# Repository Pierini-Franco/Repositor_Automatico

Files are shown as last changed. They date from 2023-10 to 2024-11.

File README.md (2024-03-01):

# Repositor Automatico

## Index

* [Description](#description)
* [Demo and overview](#demo-and-overview)
* [Notes](#notes)

# Description
Autonomus warehouse robot capable of storing and bringing goods pallets using a realtime order products. The goal is to develop a system meant to automate warehouses and track the stock of the goods, as well as the employees's orders.

# Demo and overview
MQTT broker receiving employee's order in JSON format.

https://github.com/Pierini-Franco/Repositor_Automatico/assets/105557226/09ac5b65-eae8-4226-86f4-ccc1e2ff2913

The `React app` provides a way to order multiple products in a single order. At the same time, employees can order a single product 

| Order multiples products | Order a single product |
| :---: | :---: |
| client-and-mqtt-broker-gif-1 | client-and-mqtt-broker-gif-2 |

> [!NOTE]
> 
> _The React client order is sent throught websocket to a `Node.js server`, which re-send the products order to the `MQTT broker`_.

# Notes
This project is being develop and we will be posting the latest updates.

Leave a ⭐ if you are interested in this repo!

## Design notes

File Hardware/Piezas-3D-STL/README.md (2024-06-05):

# Piezas de impresion 3D

## Index

* [Descripcion](#descripcion)
* [Piezas 3D](#piezas-3d)
* [Notas](#notas)

# Descripcion
Conjunto de piezas del proyecto de impresion 3D

# Piezas 3D

| Nombre | Vista previa |
| :---: | :---: |
| Esquinero Base 1 |  |
| Sporte Motores |  |
| Soporte Placa CNY70 |  |

# Notas

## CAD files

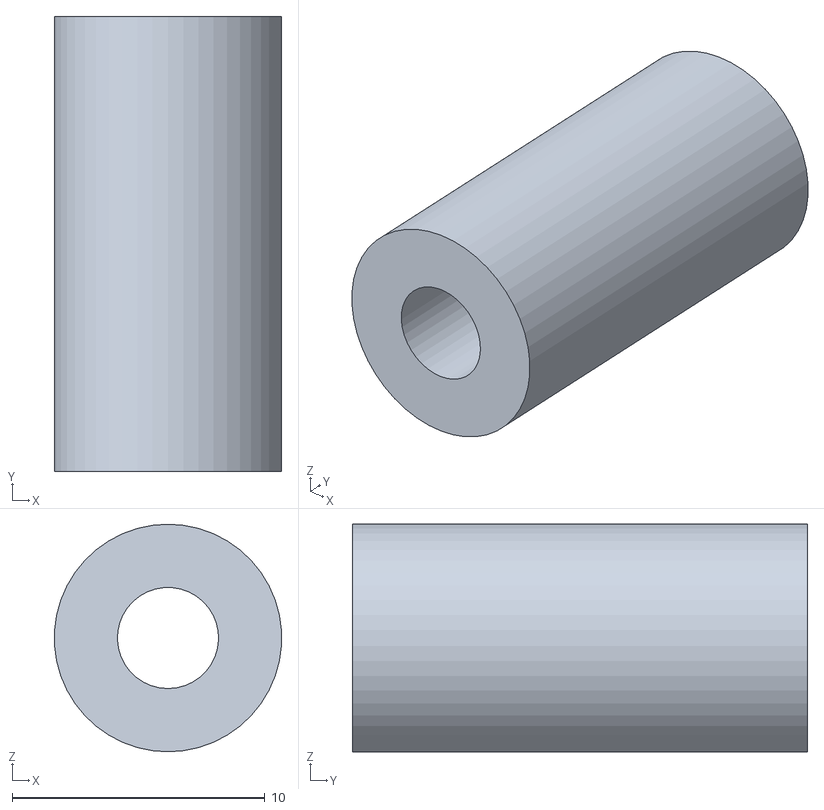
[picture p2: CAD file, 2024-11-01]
Hardware/Piezas-3D-STL/SOPORTE-PLACA-DRIVER-MAIN.STL
8.98 x 18.0 x 9.00

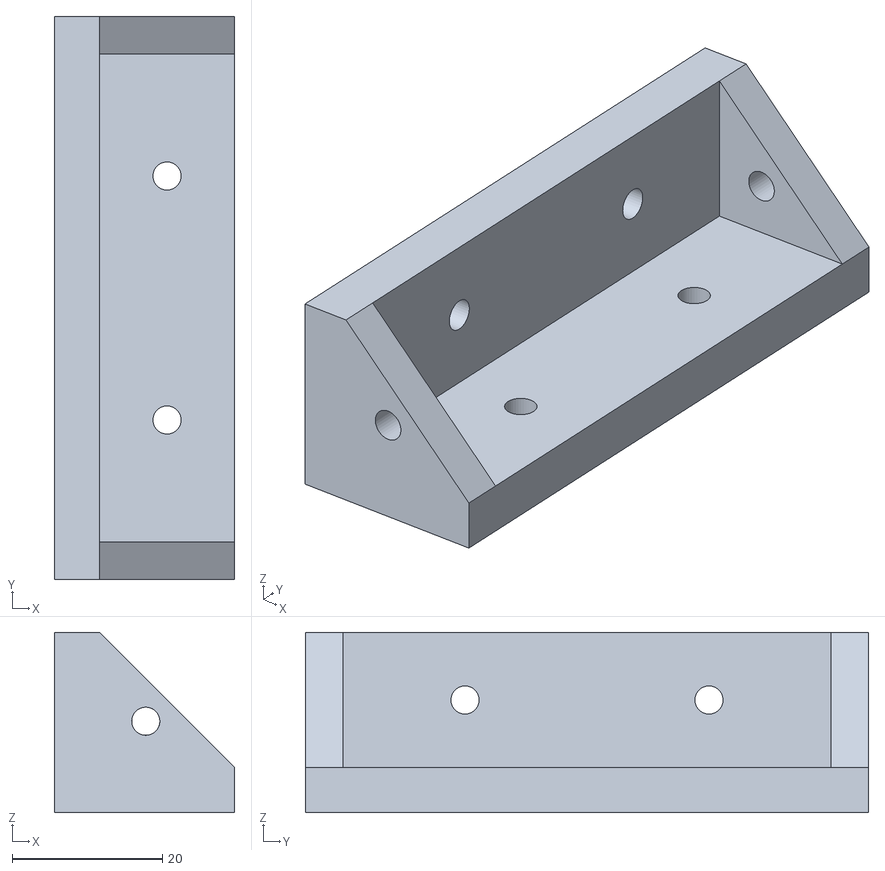
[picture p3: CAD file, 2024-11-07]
Hardware/Piezas-3D-STL/ESQUINERO-BASE-1-V2.STL
24.0 x 75.0 x 24.0

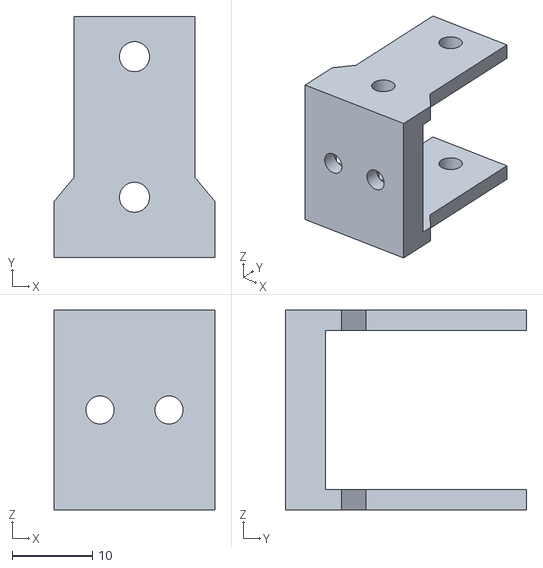
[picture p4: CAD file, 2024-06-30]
Hardware/Piezas-3D-STL/SOPORTE-MOTORES.STL
20.0 x 30.0 x 24.9

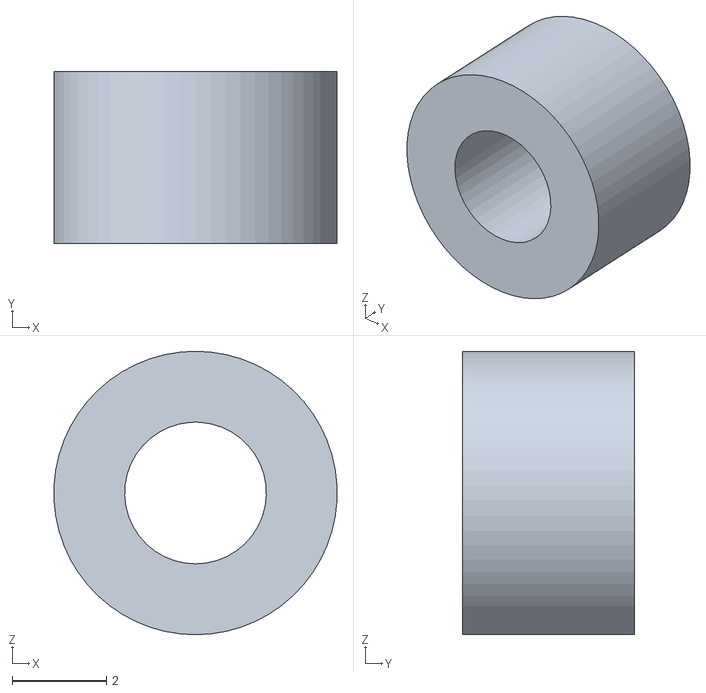
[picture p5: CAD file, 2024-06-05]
Hardware/Piezas-3D-STL/SOPORTE-PLACA-CNY70.STL
5.99 x 3.65 x 6.00

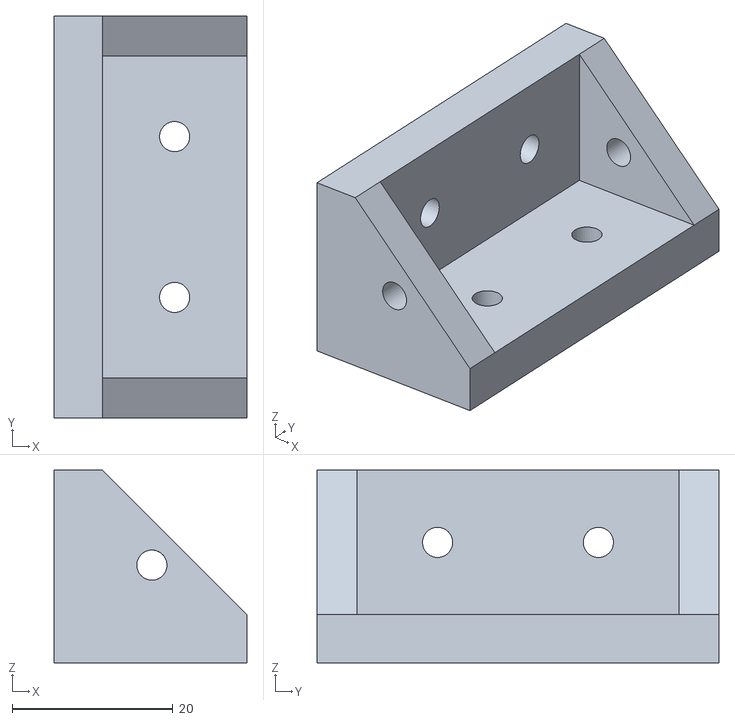
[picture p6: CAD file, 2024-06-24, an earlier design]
Hardware/Piezas-3D-STL/ESQUINERO-BASE-1.STL
24.0 x 50.0 x 24.0

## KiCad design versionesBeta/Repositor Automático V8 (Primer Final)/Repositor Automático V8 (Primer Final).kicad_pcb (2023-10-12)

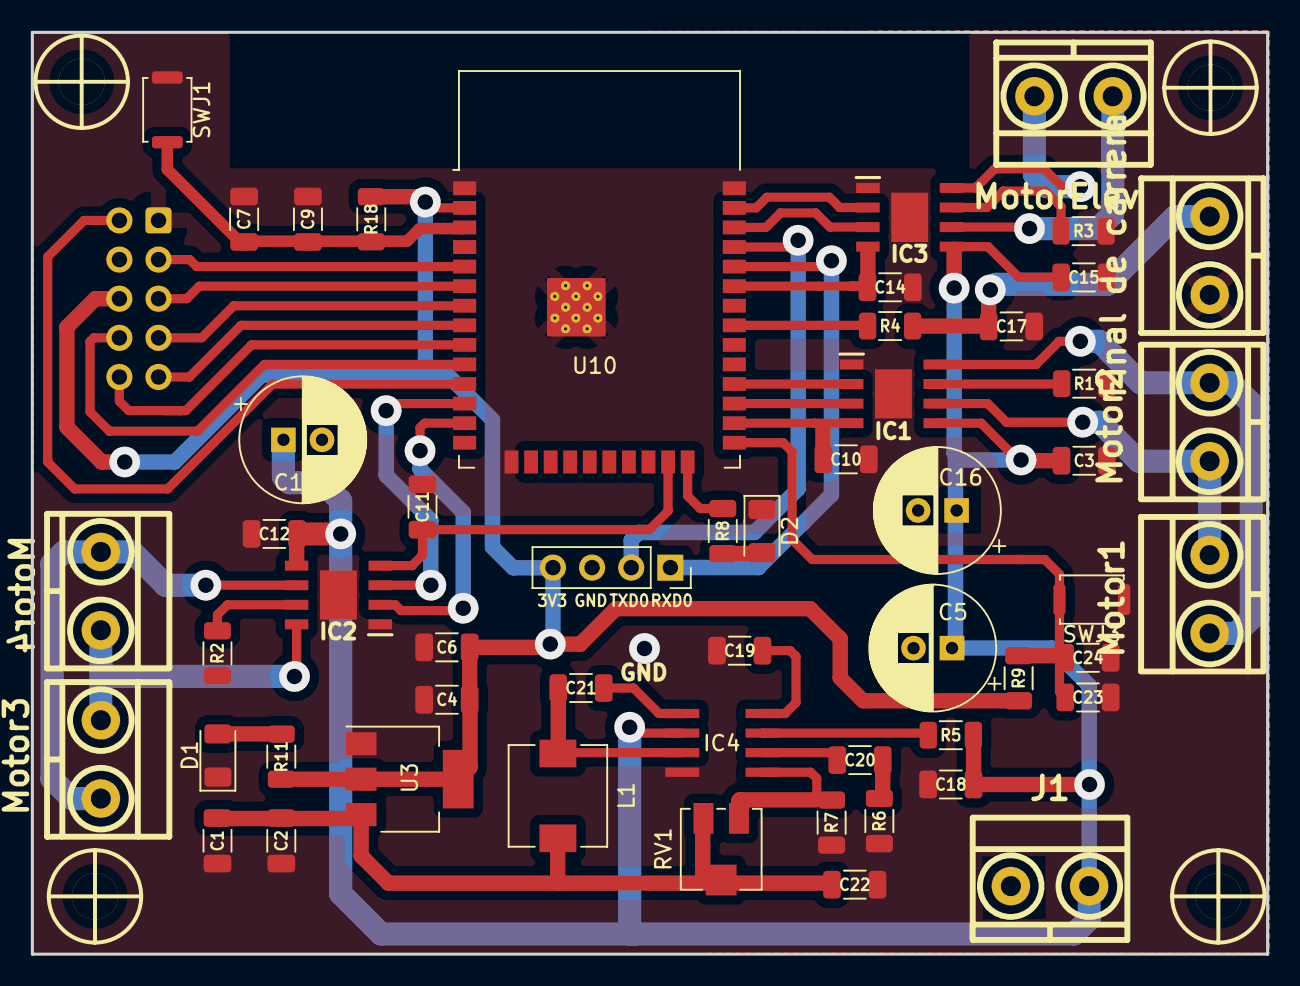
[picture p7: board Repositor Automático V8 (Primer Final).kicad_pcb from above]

Board: 2 copper layers, 80.2 x 59.8 mm, 59 parts (1 on the bottom side), 45 nets.

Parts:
C1, C6: 10u; C_1206_3216Metric
C2, C3, C4, C7, C9, C10, C11, C12, C14, C15, C17, C19, C23, C24: 0.1u; C_1206_3216Metric
C5, C13, C16: 100u; CP_Radial_D8.0mm_P2.50mm
C18, C22: 12u; C_1206_3216Metric
C20: 4.8n; C_1206_3216Metric
C21: 10n; C_1206_3216Metric
D1, D2: LED; LED_1206_3216Metric
IC1, IC2, IC3: TB67H450AFNG,EL; SOIC127P600X170-9N
IC4: MP2307; SO8-TH
J1: Alimentacion 12V; BORNERA2_AZUL
J2: UART; PinSocket_1x04_P2.54mm_Vertical
J3: Motor2; BORNERA2_AZUL
J4: Motor1; BORNERA2_AZUL
J5: Motor3; BORNERA2_AZUL
J6: Motor4; BORNERA2_AZUL
J7: MotorElev; BORNERA2_AZUL
J8: Screw_Terminal_01x10; IDC-Header_2x05_P2.54mm_Horizontal
J11: Final de carrera; BORNERA2_AZUL
L1: 2u; L_6.3x6.3_H3
R1, R2, R3: 0.22; R_1206_3216Metric
R4, R5: 100k; R_1206_3216Metric
R6, R7: 8.2k; R_1206_3216Metric
R8: 330; R_1206_3216Metric
R9, R18: 4.7k; R_1206_3216Metric
R11: 5.1k; R_1206_3216Metric
RV1: 220k; Potentiometer_Vishay_TS53YJ_Vertical
SWJ1, SWJ3: SW_MEC_5G; SW_Push_SPST_NO_Alps_SKRK
U3: AMS1117-3.3; SOT-223-3_TabPin2
U10: ESP32-WROOM-32; ESP32-WROOM-32D
hole_3mm, hole_3mm#2, hole_3mm#3, hole_3mm#4: VAL**; hole_3mm

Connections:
/3V3: C4.1, C6.1, J2.4, J8.6, R9.2, R11.1, R18.2, U3.2 (VO), U10.2 (VDD)
/5V: C1.1, C2.1, C22.1, L1.2, RV1.1, RV1.2, U3.3 (VI)
/BOOT: C23.2, C24.2, R9.1, SWJ3.2 (B), U10.25 (IO0)
/EN: C7.2, C9.2, R18.1, SWJ1.2 (B), U10.3 (EN)
/EN Elev: C14.1, IC3.4 (VREF), U10.33 (IO21)
/EnA: C10.1, IC1.4 (VREF), U10.26 (IO4)
/EnB: C11.1, IC2.4 (VREF), U10.23 (IO15)
/FC: R4.1, U10.31 (IO19)
/IN1: IC1.3 (IN1), U10.27 (IO16)
/IN2: IC1.2 (IN2), U10.28 (IO17)
/IN3: IC2.2 (IN2), U10.13 (IO14)
/IN4: IC2.3 (IN1), U10.12 (IO27)
/IN5: IC3.2 (IN2), U10.37 (IO23)
/IN6: IC3.3 (IN1), U10.36 (IO22)
/Led prueba: R8.1, U10.24 (IO2)
/RXD0: J2.1, U10.34 (RXD0/IO3)
/Sen1: J8.8, U10.10 (IO25)
/Sen2: J8.10, U10.9 (IO33)
/Sen3: J8.9, U10.8 (IO32)
/Sen4: J8.7, U10.7 (IO35)
/Sen5: J8.5, U10.6 (IO34)
/Sen6: J8.3, U10.5 (SENSOR_VN)
/Sen7: J8.2, U10.11 (IO26)
/TXD0: J2.2, U10.35 (TXD0/IO1)
/Vin: C3.1, C5.1, C12.1, C13.1, C15.1, C16.1, C18.1, IC1.5 (VM), IC2.5 (VM), IC3.5 (VM), IC4.2 (IN), J1.1, R5.1
GND: C1.2, C2.2, C3.2, C4.2, C5.2, C6.2, C7.1, C9.1, C10.2, C11.2, C12.2, C13.2, C14.2, C15.2, C16.2, C17.1, C18.2, C19.2, C22.2, C23.1, C24.1, D1.1 (K), D2.1 (K), IC1.1 (GND), IC1.9 (EP), IC2.1 (GND), IC2.9 (EP), IC3.1 (GND), IC3.9 (EP), IC4.4 (GND), J1.2, J2.3, J8.1, J11.2, R1.2, R2.2, R3.2, R6.1, R7.1, SWJ1.1 (A), SWJ3.1 (A), U3.1 (GND), U10.1 (GND), U10.15 (GND), U10.38 (GND), U10.39 (GND)
unnamed: C20.2, R6.2
unnamed: D1.2 (A), R11.2
unnamed: D2.2 (A), R8.2
unnamed: IC1.6 (OUT1), J3.1, J4.1
unnamed: IC1.8 (OUT2), J3.2, J4.2
unnamed: IC1.7 (RS), R1.1
unnamed: IC2.6 (OUT1), J5.1, J6.1
unnamed: IC2.8 (OUT2), J5.2, J6.2
unnamed: IC2.7 (RS), R2.1
unnamed: IC3.6 (OUT1), J7.1
unnamed: IC3.8 (OUT2), J7.2
unnamed: IC3.7 (RS), R3.1
unnamed: C21.1, IC4.1 (BS)
unnamed: C20.1, IC4.6 (COMP)
unnamed: IC4.7 (EN), R5.2
unnamed: IC4.5 (FB), R7.2, RV1.3
unnamed: C19.1, IC4.8 (SS)
unnamed: C21.2, IC4.3 (SW), L1.1
unnamed: C17.2, J11.1, R4.2

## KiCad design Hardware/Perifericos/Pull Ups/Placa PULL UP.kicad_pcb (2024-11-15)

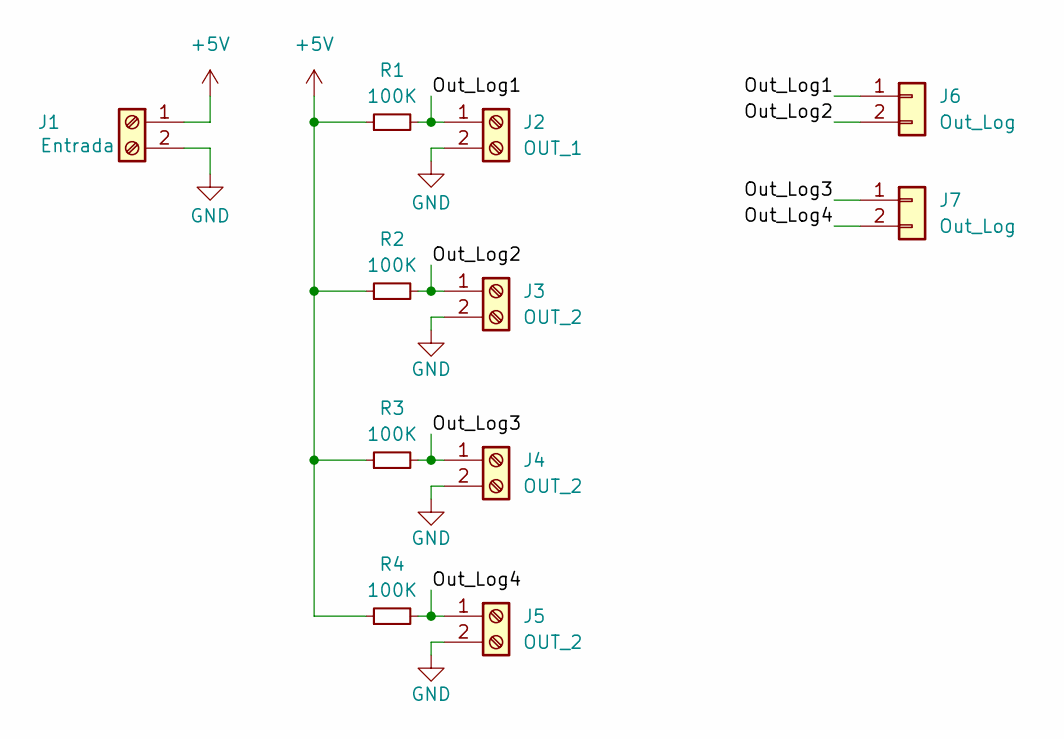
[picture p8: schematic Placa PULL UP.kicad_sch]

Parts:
J1: Entrada; BORNERA2_AZUL
J2: OUT_1; BORNERA2_AZUL
J3, J4, J5: OUT_2; BORNERA2_AZUL
J6, J7: Out_Log; PinHeader_1x02_P2.54mm_Horizontal
R1, R2, R3, R4: 100K; R_Axial_DIN0207_L6.3mm_D2.5mm_P7.62mm_Horizontal

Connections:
+5V: J1.1, R1.1, R2.1, R3.1, R4.1
/Out_Log1: J2.1, J6.1, R1.2
/Out_Log2: J3.1, J6.2, R2.2
/Out_Log3: J4.1, J7.1, R3.2
/Out_Log4: J5.1, J7.2, R4.2
GND: J1.2, J2.2, J3.2, J4.2, J5.2

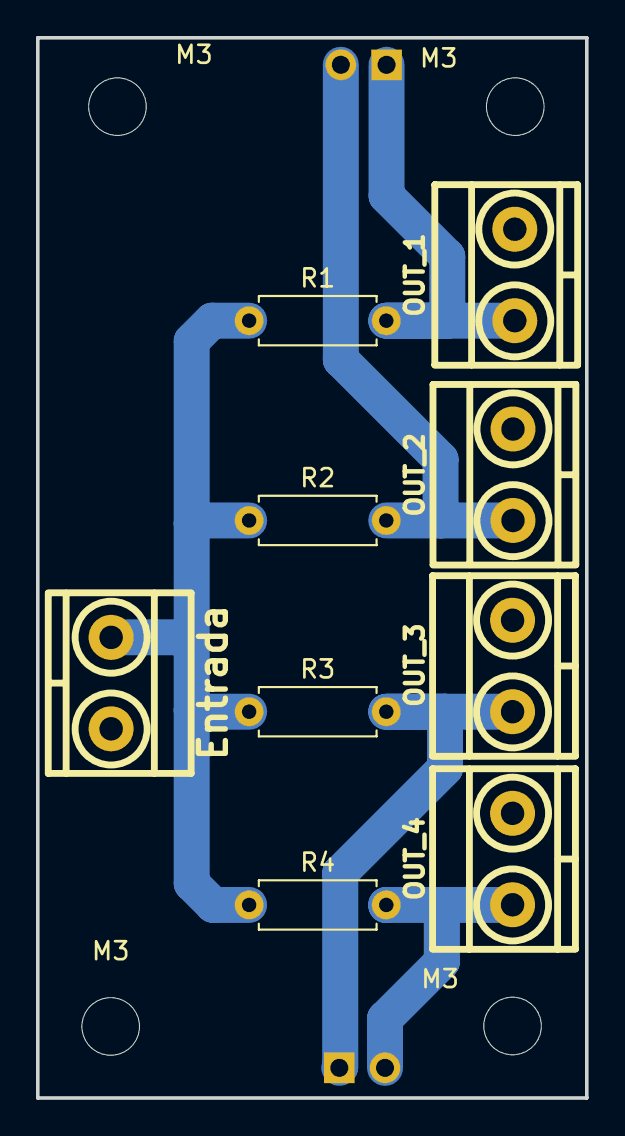
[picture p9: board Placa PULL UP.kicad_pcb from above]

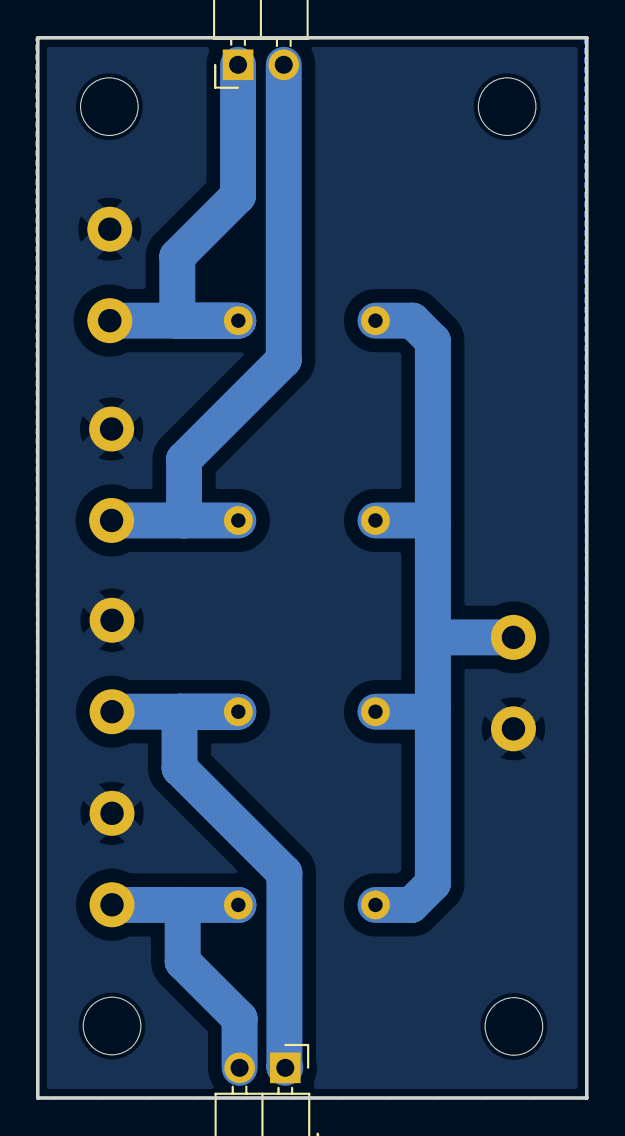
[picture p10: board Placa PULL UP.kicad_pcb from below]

Board: 2 copper layers, 30.5 x 58.9 mm, 15 parts (2 on the bottom side), 6 nets.

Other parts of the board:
M3, M3#2, M3#3, M3#4: MountingHole_3.2mm_M3

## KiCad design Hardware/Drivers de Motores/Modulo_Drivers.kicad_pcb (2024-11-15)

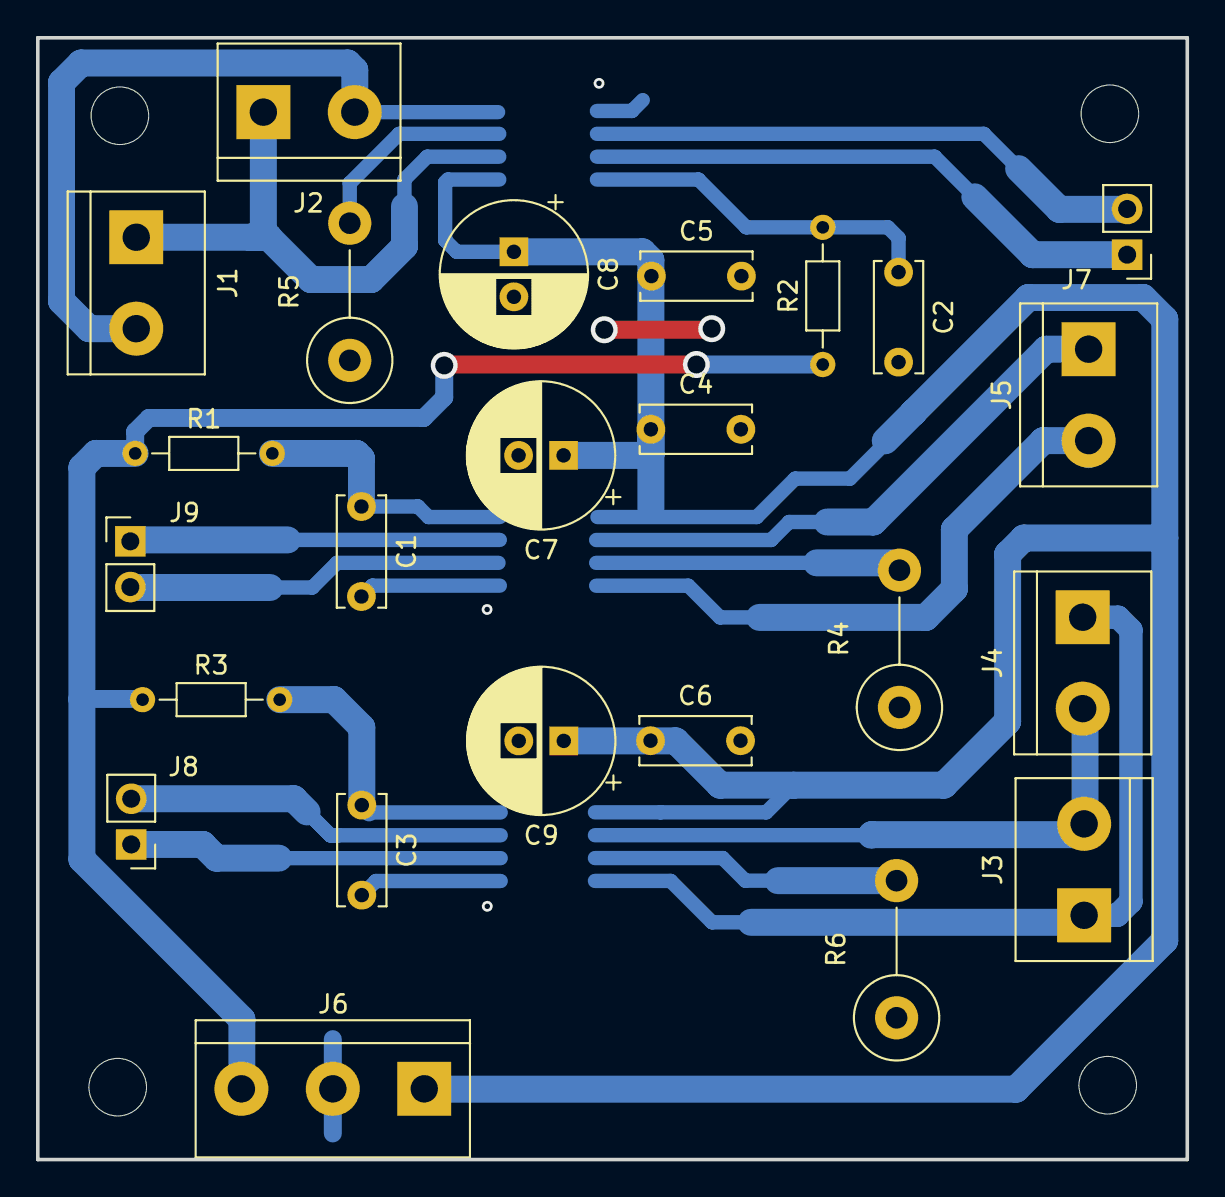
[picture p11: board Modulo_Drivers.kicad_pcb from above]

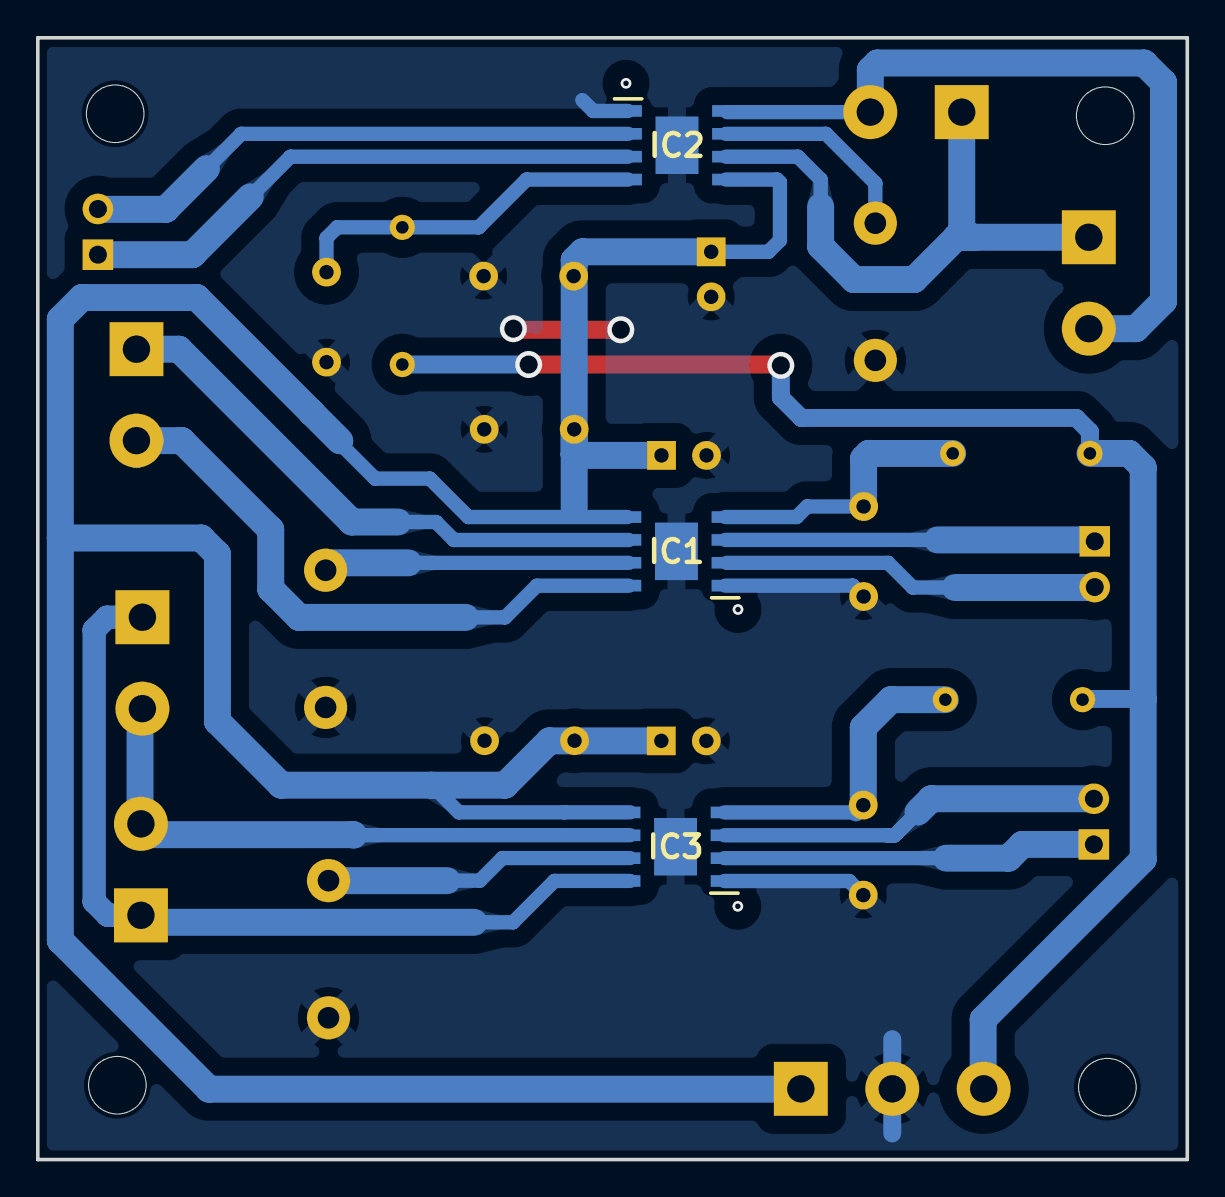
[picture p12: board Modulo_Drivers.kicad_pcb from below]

Board: 2 copper layers, 63.9 x 62.3 mm, 28 parts (3 on the bottom side), 21 nets.

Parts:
C1, C2, C3, C4, C5, C6: 0.1u; C_Disc_D6.0mm_W2.5mm_P5.00mm
C7, C8, C9: 100u; CP_Radial_D8.0mm_P2.50mm
IC1, IC2, IC3: TB67H450AFNG,EL; SOIC127P600X170-9N
J1: Motor1; TerminalBlock_bornier-2_P5.08mm
J2: Motor2; TerminalBlock_bornier-2_P5.08mm
J3: Motor3; TerminalBlock_bornier-2_P5.08mm
J4: Motor4; TerminalBlock_bornier-2_P5.08mm
J5: MotorElev; TerminalBlock_bornier-2_P5.08mm
J6: Alimentacion; TerminalBlock_bornier-3_P5.08mm
J7, J8, J9: Screw_Terminal_01x02; PinHeader_1x02_P2.54mm_Vertical
M3: MountingHole_3.2mm_M3
R1, R2, R3: 1k; R_Axial_DIN0204_L3.6mm_D1.6mm_P7.62mm_Horizontal
R4, R5, R6: 0,2; R_Axial_DIN0414_L11.9mm_D4.5mm_P7.62mm_Vertical

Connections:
/5V: J6.3, R1.1, R2.1, R3.1
/IN1: IC2.3 (IN1), J7.1
/IN2: IC2.2 (IN2), J7.2
/IN3: IC3.2 (IN2), J8.1
/IN4: IC3.3 (IN1), J8.2
/IN5: IC1.3 (IN1), J9.1
/IN6: IC1.2 (IN2), J9.2
/Vin: C4.1, C5.1, C6.1, C7.1, C8.1, C9.1, IC1.5 (VM), IC2.5 (VM), IC3.5 (VM), J6.1
GND: C1.2, C2.2, C3.2, C4.2, C5.2, C6.2, C7.2, C8.2, C9.2, IC1.1 (GND), IC1.9 (EP), IC2.1 (GND), IC2.9 (EP), IC3.1 (GND), IC3.9 (EP), J6.2, R4.1, R5.1, R6.1
unnamed: IC1.6 (OUT1), J5.1
unnamed: IC1.8 (OUT2), J5.2
unnamed: IC1.7 (RS), R4.2
unnamed: C1.1, IC1.4 (VREF), R1.2
unnamed: IC2.6 (OUT1), J1.1, J2.1
unnamed: IC2.8 (OUT2), J1.2, J2.2
unnamed: IC2.7 (RS), R5.2
unnamed: C2.1, IC2.4 (VREF), R2.2
unnamed: IC3.6 (OUT1), J3.2, J4.2
unnamed: IC3.8 (OUT2), J3.1, J4.1
unnamed: IC3.7 (RS), R6.2
unnamed: C3.1, IC3.4 (VREF), R3.2

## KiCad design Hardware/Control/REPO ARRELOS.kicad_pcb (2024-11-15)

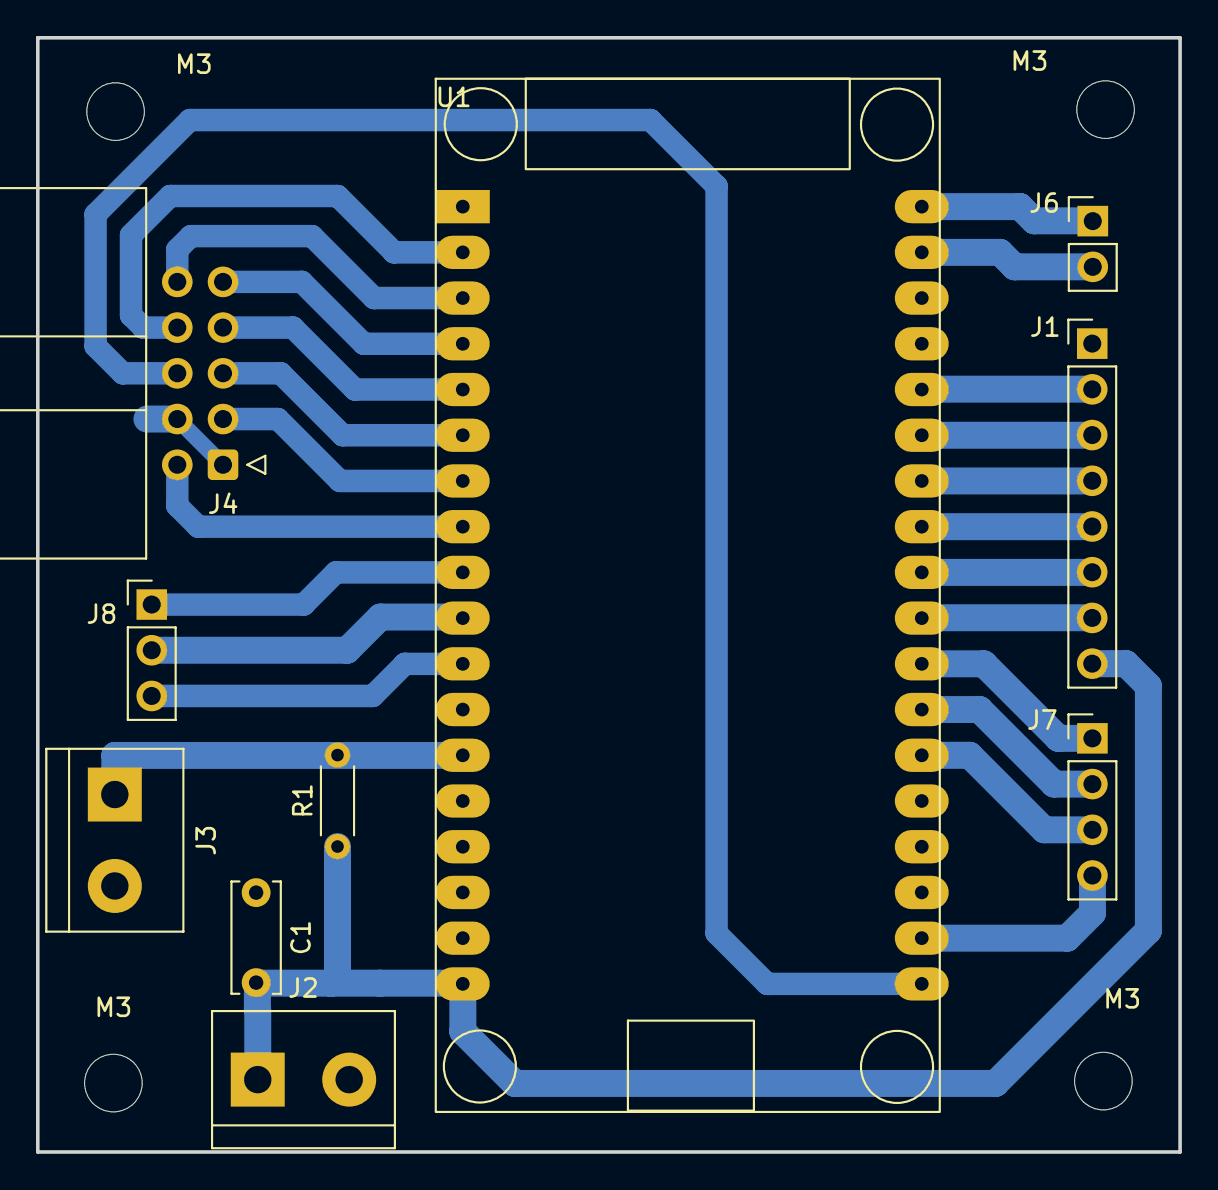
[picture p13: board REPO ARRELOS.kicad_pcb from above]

Board: 2 copper layers, 63.5 x 61.9 mm, 14 parts (0 on the bottom side), 26 nets.

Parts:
C1: 0.1u; C_Disc_D6.0mm_W2.5mm_P5.00mm
J1: Screw_Terminal_01x08; PinHeader_1x08_P2.54mm_Vertical
J2: IN STEP; TerminalBlock_bornier-2_P5.08mm
J3: FC; TerminalBlock_bornier-2_P5.08mm
J4: Screw_Terminal_01x10; IDC-Header_2x05_P2.54mm_Horizontal
J6: Screw_Terminal_01x02; PinHeader_1x02_P2.54mm_Vertical
J7: Screw_Terminal_01x04; PinHeader_1x04_P2.54mm_Vertical
J8: Screw_Terminal_01x03; PinHeader_1x03_P2.54mm_Vertical
M3, M3#2, M3#3, M3#4: MountingHole_3.2mm_M3
R1: 100k; R_Axial_DIN0204_L3.6mm_D1.6mm_P5.08mm_Horizontal
U1: ESP32_DevKit_V1_36PIN; ESP32_Devkit_V1_36pin

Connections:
/3V3: J4.6, U1.19 (3V3)
/5V: C1.2, J1.8, J2.1, R1.1, U1.18 (VIN)
/CLK: J7.4, U1.20 (CLK)
/FC: J3.1, R1.2, U1.13 (IO13)
/IN1: J1.2, U1.32 (IO21)
/IN2: J1.3, U1.31 (IO19)
/IN3: J1.4, U1.30 (IO18)
/IN4: J1.5, U1.29 (IO5)
/IN5: J1.6, U1.28 (TX2)
/IN6: J1.7, U1.27 (RX2)
/IO2(LED): J7.2, U1.25 (IO2)
/IO4: J7.1, U1.26 (IO4)
/IO14(BOOT PWM): J8.3, U1.11 (IO14)
/IO15(BOOT PWM): J7.3, U1.24 (IO15)
/IO22: J6.2, U1.35 (IO22)
/IO23: J6.1, U1.36 (IO23)
/IO26: J8.1, U1.9 (IO26)
/IO27: J8.2, U1.10 (IO27)
/Sen1: J4.8, U1.2 (SENSOR_VP)
/Sen2: J4.10, U1.3 (SENSOR_VN)
/Sen3: J4.9, U1.4 (IO34)
/Sen4: J4.7, U1.5 (IO35)
/Sen5: J4.5, U1.6 (IO32)
/Sen6: J4.3, U1.7 (IO33)
/Sen7: J4.2, U1.8 (IO25)
GND: C1.1, J1.1, J2.2, J3.2, J4.1, J4.4, U1.17 (GND)

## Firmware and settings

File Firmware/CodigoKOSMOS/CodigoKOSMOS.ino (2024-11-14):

#include <WiFi.h>
#include <PubSubClient.h>
#include "BluetoothSerial.h"
#define DEBUG 0
#define IN6 16
#define IN5 17
#define IN4 18
#define IN3 19
#define IN2 21
#define IN1 22
#define PIN_CNY1 36
#define PIN_CNY2 39
#define PIN_CNY3 34
#define PIN_CNY4 35
#define PIN_CNY5 32
#define PIN_CNY6 33
#define PIN_CNY7 25
#define FC1 4
#define FC2 26
#define FC3 27
#define led_ESP 2

#define derecha 1
#define izquierda 0
#define arriba 1
#define abajo 0

//Hardware
int x = 0; 
float anterior = 0, espera = 10, TIME;
int umbral = 1000; // negro > 1000
int var;
int ARRANCA;
int nivel;  
int destino;
int estado; 

// Canales PWM
#define CHA1 4
#define CHA2 5
#define CHB1 6
#define CHB2 7
#define CHC1 8
#define CHC2 9

#define FRQ 1000
#define RES 8
#define VEL 70


//Futbolista
/*int CT;
const int canalPWM0 = 0;
const int canalPWM1 = 1;
const int frecuencia = 10000;
const int resolucion = 8;  // Ciclo de trabajo de 0 a 255
String incoming, angulo;
char angulo1;
int modulo, boton;
BluetoothSerial BT;  // Objeto Bluetooth
*/
//conexion wifi
// WiFi 
//const char *ssid = "MovistarFibra-F76AF0"; // Enter your WiFi name
//const char *password = "cnvpmJkmdYrtNfX4ts2G";  // Enter WiFi password
//const char *ssid = "Franco's Galaxy A11"; // Introduce el nombre de tu WiFi 
//const char *password = "gkme2498";  // Introduce tu contraseña WiFi 
const char *ssid = "Taller_Electronica";
const char *password = "robotica";

WiFiClient espClient;                        // Definir espClient como un objeto de la clase WiFiClient. 


// MQTT Broker
int PAYLOADINT;
const char *mqtt_broker = "broker.emqx.io";
const char *topic = "KOSMOS"; //nombre a cambiar (nombre broker)
const char *mqtt_username = "KOSMOS_ESP"; //nombre a cambiar (nombre usuario)
const char *mqtt_password = "Repositor1"; //nombre a cambiar (nombre contraseña)
const int mqtt_port = 1883;
PubSubClient client(espClient);              // Definir espClient como objeto de la clase PubSubClient.


void setup() {
  Serial.begin(115200);         // Inicialización de la conexión en serie para la depuración
  pinMode(IN6, OUTPUT);  
  pinMode(IN5, OUTPUT);  
  pinMode(IN4, OUTPUT);  
  pinMode(IN3, OUTPUT);
  pinMode(IN2, OUTPUT);
  pinMode(IN1, OUTPUT);
  pinMode(led_ESP, OUTPUT);
  pinMode(PIN_CNY1, INPUT);
  pinMode(PIN_CNY2, INPUT);
  pinMode(PIN_CNY3, INPUT);
  pinMode(PIN_CNY4, INPUT);
  pinMode(PIN_CNY5, INPUT);
  pinMode(PIN_CNY6, INPUT);
  pinMode(PIN_CNY7, INPUT); 
  pinMode(FC1, INPUT); 
  pinMode(FC2, INPUT);
  pinMode(FC3, INPUT);

  //PWM
  ledcSetup(CHA1, FRQ, RES);
  ledcSetup(CHA2, FRQ, RES);
  ledcSetup(CHB1, FRQ, RES);
  ledcSetup(CHB2, FRQ, RES);
  ledcSetup(CHC1, FRQ, RES);
  ledcSetup(CHC2, FRQ, RES);

  ledcAttachPin(IN1, CHA1);
  ledcAttachPin(IN2, CHA2);
  ledcAttachPin(IN3, CHB1);
  ledcAttachPin(IN4, CHB2);
  ledcAttachPin(IN5, CHC1);
  ledcAttachPin(IN6, CHC2);
  
  //Conexion WIFI

  WiFi.begin(ssid, password);
  while (WiFi.status() != WL_CONNECTED) {
    delay(500);
    Serial.println("Connecting to WiFi..");
  }
  Serial.println("Connected to WiFi..");

  //Inicialización broker
  client.setServer(mqtt_broker, mqtt_port);
  client.setCallback(callback);
  while (!client.connected()) {
    String client_id = "esp32-client-";
    client_id += String(WiFi.macAddress());
    Serial.printf("The client %s connects to the public MQTT broker\n", client_id.c_str());
    if (client.connect(client_id.c_str(), mqtt_username, mqtt_password)) {
        Serial.println("Public EMQX MQTT broker connected");
        client.publish("Altura", "Hi EMQX I'm ESP32 ^^"); // Publish message upon successful connection
        digitalWrite (led_ESP, HIGH); 
    } else {
        Serial.print("failed with state ");
        Serial.print(client.state());
        delay(2000);
    }
    client.subscribe("Altura");
    client.subscribe("Direccion");
    client.subscribe("Iniciacion");
    client.subscribe("Estado");
  }

  //PARA FUTBOLISTA
  //BT.begin("ESP32_Kosmos");  // Nombre de su dispositivo Bluetooth y en modo esclavo
 /* ledcAttachPin(ENA, canalPWM0);  // hasta aca decia el video
  ledcAttachPin(ENB, canalPWM1);
  ledcSetup(canalPWM0, frecuencia, resolucion);
  ledcSetup(canalPWM1, frecuencia, resolucion);
 */
 //Charla esp
  client.publish(topic, "Hi, I'm ESP32 ^^");
  client.subscribe(topic);
}
void adelante() {
  ledcWrite(CHA1, VEL);
  ledcWrite(CHA2, 0);
  ledcWrite(CHB1, VEL);
  ledcWrite(CHB2, 0);
}
void atras() {
  ledcWrite(CHA1, 0);
  ledcWrite(CHA2, VEL);
  ledcWrite(CHB1, 0);
  ledcWrite(CHB2, VEL);
}
void doblarIzquierda() {
  ledcWrite(CHA1, VEL);
  ledcWrite(CHA2, 0);
  ledcWrite(CHB1, 0);
  ledcWrite(CHB2, 0);
}
void doblarDerecha() {
  ledcWrite(CHA1, 0);
  ledcWrite(CHA2, 0);
  ledcWrite(CHB1, VEL);
  ledcWrite(CHB2, 0);
}
void quieto(){
  ledcWrite(CHA1, 0);
  ledcWrite(CHA2, 0);
  ledcWrite(CHB1, 0);
  ledcWrite(CHB2, 0);
  ledcWrite(CHC1, 0);
  ledcWrite(CHC2, 0);
}
void subir(){
  ledcWrite(CHC1, VEL);
  ledcWrite(CHC2, 0);
}
void bajar(){
  ledcWrite(CHC1, 0);
  ledcWrite(CHC2, VEL);
}
bool tomar_objeto(int fc1){
  while (!fc1) subir(); 
  quieto(); 
  if (fc1) var = 1; 
  return var; 
}
int dejar_objeto(int fc1){
  while (fc1) bajar(); 
  quieto(); 
  if (!fc1) var = 1; 
  return var; 
} 
void giro180(int direccion){
  //arranca a girar, cuando volviste a leer blanco para tanto tiempo.
  TIME = millis();
  if (direccion == derecha) doblarDerecha(); 
  else doblarIzquierda();
  if(TIME - anterior > espera){
      anterior = TIME;

  while (!centro_negro()){
    if(direccion == derecha) doblarDerecha();
    else doblarIzquierda();
    }
    quieto();
  }
  if(TIME - anterior > espera){
    anterior = TIME;
    quieto(); 
  }
}
/*
void pruebaMotores(){
      digitalWrite(IN6, LOW );
        digitalWrite(IN5, HIGH);
        digitalWrite(IN4, LOW);
        digitalWrite(IN3, HIGH);
        digitalWrite(IN2, LOW);
        digitalWrite(IN1, HIGH);
        digitalWrite(ENA, HIGH);
        digitalWrite(ENB, HIGH);
        digitalWrite(ENC, HIGH);
}

void futbolista(){
  if (BT.available()) {
    incoming = BT.readStringUntil('#');
    angulo = incoming.substring(0, 1);
    angulo1 = angulo[0];
    boton = incoming.substring(1, 2).toInt();
  }
  Serial.println(incoming);
  //Serial.print("Recibido: ");
  if (DEBUG) BT.println(incoming);
  switch (angulo1) {
    case 'N':
      {
        digitalWrite(IN4, LOW);
        digitalWrite(IN3, HIGH);
        digitalWrite(IN2, LOW);
        digitalWrite(IN1, HIGH);
        if (DEBUG) BT.println("Adelante");
      }
      break;
    case 'S':
      {
        digitalWrite(IN4, HIGH);
        digitalWrite(IN3, LOW);
        digitalWrite(IN2, HIGH);
        digitalWrite(IN1, LOW);
        if (DEBUG) BT.println("Atras");
      }
      break;
    case 'E':
      {
        digitalWrite(IN4, LOW);

        digitalWrite(IN3, HIGH);
        digitalWrite(IN2, HIGH);
        digitalWrite(IN1, LOW);
        if (DEBUG) BT.println("Giro Derecha");
      }
      break;
    case 'W':
      {
        digitalWrite(IN4, HIGH);
        digitalWrite(IN3, LOW);
        digitalWrite(IN2, LOW);
        digitalWrite(IN1, HIGH);
        if (DEBUG) BT.println("Giro Izquierda");
      }
      break;
    case 'B':
      {
        digitalWrite(IN4, HIGH);
        digitalWrite(IN3, LOW);
        digitalWrite(IN2, LOW);
        digitalWrite(IN1, LOW);
        if (DEBUG) BT.println("PARA ATRAS A LA DERECHA");
      }
      break;
    case 'C':
      {
        digitalWrite(IN4, HIGH);
        digitalWrite(IN3, HIGH);
        digitalWrite(IN2, HIGH);
        digitalWrite(IN1, LOW);
        if (DEBUG) BT.println("PARA ATRAS A LA IZQUIERDA");
      }
      break;
    case 'A':
      {
        digitalWrite(IN4, LOW);
        digitalWrite(IN3, HIGH);
        digitalWrite(IN2, HIGH);
        digitalWrite(IN1, HIGH);
        if (DEBUG) BT.println("PARA ADELANTE A LA DERECHA");
      }
      break;
    case 'D':
      {
        digitalWrite(IN4, HIGH);
        digitalWrite(IN3, HIGH);
        digitalWrite(IN2, LOW);
        digitalWrite(IN1, HIGH);
        if (DEBUG) BT.println("PARA ADELANTE A LA IZQUIERDA");
      }
      break;
    case '0':
      {
        digitalWrite(IN4, LOW);
        digitalWrite(IN3, LOW);
        digitalWrite(IN2, LOW);
        digitalWrite(IN1, LOW);
        if (DEBUG) BT.println("FRENA");
      }
      break;
  }
  switch (boton)  // vamos a darle velocidad con esto.
  {
    case 4:
      {
        CT = 255;
        ledcWrite(canalPWM0, CT);
        ledcWrite(canalPWM1, CT);
      }
      break;
    case 3:
      {
        CT = 216;
        ledcWrite(canalPWM0, CT);
        ledcWrite(canalPWM1, CT);
      }
      break;
    case 2:
      {
        CT = 192;
        ledcWrite(canalPWM0, CT);
        ledcWrite(canalPWM1, CT);
      }
      break;
    case 1:
      {
        CT = 127;
        ledcWrite(canalPWM0, CT);
        ledcWrite(canalPWM1, CT);
      }
      break;
    case 0:
      {
        CT = 0;
        ledcWrite(canalPWM0, CT);
        ledcWrite(canalPWM1, CT);
      }
  }
}*/
void lecturaCNY_prueba() {
  Serial.println(analogRead(PIN_CNY1));
  Serial.println(analogRead(PIN_CNY2));
  Serial.println(analogRead(PIN_CNY3));
  Serial.println(analogRead(PIN_CNY4));
  Serial.println(analogRead(PIN_CNY5));
  Serial.println(analogRead(PIN_CNY6));
  Serial.println(analogRead(PIN_CNY7));
  delay(200);
}
bool es_negro(int pin){
  int sumatoria = 0; 
  for (int i=0; i<5; i++){
    sumatoria += analogRead(pin);  
  }
  int promedio = sumatoria / 5;
  return promedio > umbral;
}

bool centro_negro(){
  var = es_negro(PIN_CNY3) && es_negro(PIN_CNY4) && es_negro(PIN_CNY5); 
  return var;
}

bool bifurcacion(){
  var = es_negro(PIN_CNY6) && es_negro(PIN_CNY7); 
  return var;
}

bool cod_llegue(){
  var = es_negro(PIN_CNY1) && es_negro(PIN_CNY2) && es_negro(PIN_CNY3) && es_negro(PIN_CNY4) && es_negro(PIN_CNY5) && es_negro(PIN_CNY6) && es_negro(PIN_CNY7); 
  return var;
}

bool cod_volver(){
  var =es_negro(PIN_CNY1) && es_negro(PIN_CNY3) && es_negro(PIN_CNY4) && es_negro(PIN_CNY5) && es_negro(PIN_CNY6);  
  return var;
}

bool cod_izq(){
  var =es_negro(PIN_CNY1) && es_negro(PIN_CNY2) && es_negro(PIN_CNY3) && es_negro(PIN_CNY4) && es_negro(PIN_CNY5);  
  return var;
}

bool cod_salir(){
  var =es_negro(PIN_CNY2) && es_negro(PIN_CNY3) && es_negro(PIN_CNY4) && es_negro(PIN_CNY5) && es_negro(PIN_CNY7); 
  return var;
}

int contador(){
  //contador, devuelve derecha o izquierda y lee sensores para ver que llego
  //tomar dato de la base de datos (¿Cuando doblo, en que bifurcación?)
  //esto es para IR al destino

  //destino = dato_base;   
  if (bifurcacion()){
    int x = x+1; 
  }
  if (x == destino){
    doblar(derecha); 
    return 1; 
  } 
}

void doblar(int direccion) {
TIME = millis();
  if (direccion == derecha) doblarDerecha(); 
  else doblarIzquierda();
  if(TIME - anterior > espera){
      anterior = TIME;

  while (!centro_negro()){
    if(direccion == derecha) doblarDerecha();
    else doblarIzquierda();
    }
  }
  quieto();
  if(TIME - anterior > espera){
    anterior = TIME; 
    quieto();
  }
}

void salir (int ARRANCA){
  TIME = millis();
  if (ARRANCA){
  while (!cod_salir()){
  atras(); 
  }  
  quieto();   
  if(TIME - anterior > espera)
    {
      anterior = TIME; 
      giro180(derecha);  
    }
  }
}

void volver (){
  TIME = millis();
  while (!cod_volver()) atras();   
  quieto();   
  if(TIME - anterior > espera)
    {
      anterior = TIME; 
      giro180(izquierda);  
    }
  }


void giro_vuelta(){
  TIME = millis();
  while (!cod_izq) doblarIzquierda();
  quieto(); 
  if(TIME - anterior > espera){
    anterior = TIME; 
    quieto();
  }
} 

int nivelar_pala (int nivel, int fc2){
  //Corregir
  // Me va a entrar por base de datos en q gondola (arriba o abajo) va el objeto. Para subir y bajar vamos a usar tiempo y alguna barrera fisica
  TIME = millis();
  int espera1 = 500; //a definir cuando sepamos cuanto es necesario para poner bien la pala
  if(TIME - anterior > espera1){
  anterior = TIME;
  if (nivel==1){
    while (!fc2){
    subir();
    var = 1;  
    }
  }  
  else{ 
    var = 0; 
    } 
  }
  quieto(); 
  if(TIME - anterior > espera){
    anterior = TIME; 
    quieto();
  }
  return var; 
}
void devolver_pala(int fc3){
  TIME = millis();
  while (!fc3){
  bajar(); 
  }
  quieto();
  if(TIME - anterior > espera){
    anterior = TIME; 
    quieto();
  }
}
void depositar_objeto(){  

  //pruebaMotores();  
  //FC da 1 cuando detecta algo
  //Salir de la estacion y nivelar pala
  //Salir de la estacion: poner marca para hacer giro 180°, establecer si estoy yendo o volviendo 
  //Por ahora estoy programando para ir a buscar algo, no traerlo
  //La base de datos me va a decir: gondola a la que ir, altura, yendo a bucar o trayendo, me dice ARRANCA

  //TODOOO ESTO ES PARA IR
  //int ARRANCA = 1;
  //int nivel = 1;  
  //ARRANCA, nivel me lo va a dar la base de datos
  int estado_objeto = 0; 
  int estado_pala = 0; 
  int fc1 = 0;
  int fc2 = 0;
  int fc3 = 0;
   
  fc1 = digitalRead(FC1);
  fc2 = digitalRead(FC2);
  fc3 = digitalRead(FC3);  
  if (ARRANCA == 1){
  if (tomar_objeto(fc1)){
  salir (ARRANCA);
  estado_pala = nivelar_pala(nivel, fc2); 
    } 
  while (centro_negro()){
  if (contador()){
    while (!cod_llegue()){
    adelante();
    }
    quieto(); 
   estado_objeto = dejar_objeto(fc1); 
  }
  else {adelante();}
  }

  //VOLVEEER
  if (estado_objeto){
 volver();  
  }
  while (!cod_llegue()) adelante(); 
  quieto(); 
  giro_vuelta(); 
  while (!cod_llegue()) adelante();
  quieto(); 
  if (estado_pala) devolver_pala(fc3);
  quieto();  
  }
}

void extraer_objeto(){

  //int ARRANCA = 1;
  int nivel = 0;
  int destino = 2;   
  //ARRANCA, nivel me lo va a dar la base de datos
  //IR
  int estado_objeto = 0; 
  int fc1 = 0;
  int fc2 = 0;
  int fc3 = 0;
   
  fc1 = digitalRead(FC1);
  fc2 = digitalRead(FC2);
  fc3 = digitalRead(FC3);  

  if (ARRANCA){
  salir (ARRANCA);
  int estado_pala = nivelar_pala(nivel, fc2); 
  while (centro_negro()){
  if (contador()){
    while (!cod_llegue()){
    adelante();
    }
    quieto(); 
    estado_objeto = tomar_objeto(fc1); 
  }
  else adelante();
  }

  //VOLVER
  if (estado_objeto){
 volver();  
  }
  while (!cod_llegue()) adelante(); 
  quieto(); 
  giro_vuelta(); 
  while (!cod_llegue()) adelante();
  quieto();
  dejar_objeto(fc1); 
  quieto(); 
  }
}
void callback(char *topic, byte *payload, unsigned int length) {
  //La base de datos me va a decir: gondola a la que ir, altura, yendo a bucar o trayendo, me dice ARRANCA
  //Hacer otros if con otros topicos para las otras cosas a guardar. Hace un topico, confirma y va a otro topico.
  if (strcmp (topic, "Altura")==0){
    char payload_string[ length + 1]; 
    memcpy (payload_string, payload, length);  
    payload_string[length] = '\0'; 
    PAYLOADINT = atoi(payload_string);
    Serial.println(PAYLOADINT); 
    nivel = PAYLOADINT; 
  }
  else if (strcmp (topic, "Direccion")==0){
    char payload_string[ length + 1]; 
    memcpy (payload_string, payload, length); 
    payload_string[length] = '\0'; 
    PAYLOADINT = atoi(payload_string); 
    Serial.println(PAYLOADINT);
    destino = PAYLOADINT; 
  }
  else if (strcmp (topic, "Estado")==0){
    char payload_string[ length + 1]; 
    memcpy (payload_string, payload, length); 
    payload_string[length] = '\0'; 
    PAYLOADINT = atoi(payload_string); 
    Serial.println(PAYLOADINT);
    estado = PAYLOADINT; 
  }
    else if (strcmp (topic, "Iniciacion")==0){
    char payload_string[ length + 1]; 
    memcpy (payload_string, payload, length); 
    payload_string[length] = '\0'; 
    PAYLOADINT = atoi(payload_string); 
    Serial.println(PAYLOADINT);
    ARRANCA = PAYLOADINT; 
  }
}

void loop() {
  //int deposito = 1; 
  //Pedirle a base de datos si deposito o extraigo
  client.loop();
  estado = 0; 
  if (estado) depositar_objeto(); 
  else extraer_objeto();
  //Serial.println ("Hola");  
  //pruebaMotores(); 

}

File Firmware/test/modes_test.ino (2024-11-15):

#include "BluetoothSerial.h"
// configuramos el Serial Bluetooth
#if !defined(CONFIG_BT_ENABLED) || !defined(CONFIG_BLUEDROID_ENABLED)
#error Bluetooth is not enabled! Please run `make menuconfig` to and enable it
#endif

BluetoothSerial SerialBT;

/*ESP32*/
#define DEBUG 1
// Sensores CNY70
#define PIN_CNY_1 36
#define PIN_CNY_2 39
#define PIN_CNY_3 34
#define PIN_CNY_4 35
#define PIN_CNY_5 32
#define PIN_CNY_6 33
#define PIN_CNY_7 25
#define PIN_PULSADOR_CONFIRM 13
#define PIN_PULSADOR_MODE 8

#define TICK_CNY70 150
#define TICK_MODE 150
int currentTimeCNY70 = 0;
int currentTimeMode = 0;
bool debug_cny70;
int count_mode = 0;

// Par de motores
const int PIN_PMOTORESa_1 = 22; 
const int PIN_PMOTORESa_2 = 21;
const int PIN_PMOTORESb_1 = 19; 
const int PIN_PMOTORESb_2 = 18;
// PWM
const int CHa_1 = 4;
const int CHa_2 = 5;
const int CHb_1 = 6;
const int CHb_2 = 7;
const int FRQ = 10000;
const int RES = 8;

int PINES_CNY[7] = {PIN_CNY_1, PIN_CNY_2, PIN_CNY_3, PIN_CNY_4, PIN_CNY_5, PIN_CNY_6, PIN_CNY_7};
int pesos[7] = {-8, -4, -2, 1, 2, 4, 8}; // pesos en base exponencial 2
int lecturas_cny[7];
int suma_ponderada = 0;
int error = 0;
int error_previo = 0;
int pid_output = 0;
float Kp = 2; // Kp tiene que ser siempre mayor a 1
float Ki;
float Kd;
int derivada = 0;

// rango de velocidad
int vel_min = 0;  
int vel_max = 45;
int vel_base = 160; // velocidad crucero
int vel_pid = 0;
// rango de lecturas
int pid_min = 10000;
int pid_max = -10000;

void Adelante(int vel, int ch_1, int ch_2){
  ledcWrite(ch_1, vel);
  ledcWrite(ch_2, 0);
}

void Atras(int vel, int ch_1, int ch_2){
  ledcWrite(ch_1, 0);
  ledcWrite(ch_2, vel);
}

// ej.: Adelante(pid_output, CHa_1, CHa_2); par de motor 1
// ej.: Atras(pid_output, CHb_1, CHb_2); par de motor 2

void setup() {
  SerialBT.begin("KOSMOS");
  Serial.begin(115200);
  // caracteristicas canal PWM & enlace con pines salida
  ledcAttachChannel(PIN_PMOTORESa_1, FRQ, RES, CHa_1);
  ledcAttachChannel(PIN_PMOTORESa_2, FRQ, RES, CHa_2);
  ledcAttachChannel(PIN_PMOTORESb_1, FRQ, RES, CHb_1);
  ledcAttachChannel(PIN_PMOTORESb_2, FRQ, RES, CHb_2);
  
  for(int i; i <= 6; i++){
    pinMode(PINES_CNY[i], INPUT);
  }
  pinMode(LED_BUILTIN, OUTPUT);
  pinMode(PIN_PULSADOR_CONFIRM, INPUT);
  while((digitalRead(PIN_PULSADOR_CONFIRM)) == 1){
    digitalWrite(LED_BUILTIN, HIGH);
    if((digitalRead(PIN_PULSADOR_MODE)) == true){
      digitalWrite(LED_BUILTIN, LOW);
      if(millis() > currentTimeMode + TICK_MODE){
        currentTimeMode = millis();
        count_mode++;
        if(count_mode > 2) count_mode = 1;
      }
    }
  }
  digitalWrite(LED_BUILTIN, LOW);
}

void loop() {
  switch(count_mode){
    case 1:
      while(true){
        Adelante(150, PIN_PMOTORESa_1, PIN_PMOTORESa_2); // par motor a; par izquierdo
        Adelante(150, PIN_PMOTORESb_1, PIN_PMOTORESb_2); // par motor b; par derecho
      }
      break;

    case 2:
      while(true){
        debug_cny70 = false;
        suma_ponderada = 0;

        if(millis() > currentTimeCNY70 + TICK_CNY70){
          currentTimeCNY70 = millis();
          debug_cny70 = true;
        }

        if(debug_cny70){
          SerialBT.print(" ");
          SerialBT.println("Lecturas: "); 
        }

        for(int i = 0; i <= 6; i++){
          lecturas_cny[i] = analogRead(PINES_CNY[i]);
          suma_ponderada = suma_ponderada + (lecturas_cny[i] * pesos[i]);
          if(debug_cny70){
            SerialBT.println(lecturas_cny[i]);
          }
        }

        /*Calculo error y salida PID*/
        error = suma_ponderada;
        pid_output = (Kp * error);

        /*Mapear salida PID para valor velocidad de correccion*/
        vel_pid = map(pid_output, pid_min, pid_max, vel_min, vel_max);
        if(pid_output < pid_min) pid_min = pid_output;
        if(pid_output > pid_max) pid_max = pid_output;
  
        vel_pid = constrain(vel_pid, 0, 255);

        if(DEBUG) Serial.print("Velocidad pid: ");
        if(DEBUG) Serial.println(vel_pid);
        
        /*Determinar sentido y aplicar velocidad*/
        if(pid_output >= 0){
          Adelante((vel_base + vel_pid), PIN_PMOTORESa_1, PIN_PMOTORESa_2); // par motor a; par izquierdo
          Adelante((vel_base - vel_pid), PIN_PMOTORESb_1, PIN_PMOTORESb_2); // par motor b; par derecho
        }
        else if(pid_output < 0){
          Adelante((vel_base - vel_pid), PIN_PMOTORESa_1, PIN_PMOTORESa_2); // par motor a; par izquierdo
          Adelante((vel_base + vel_pid), PIN_PMOTORESb_1, PIN_PMOTORESb_2); // par motor b; par derecho
        }

        if(DEBUG){
          Serial.println(" ");
          Serial.print("Suma ponderada: ");
          Serial.println(suma_ponderada);
          Serial.print("Error: ");
          Serial.println(error);
          Serial.print("PID: ");
          Serial.println(pid_output);
          Serial.print("Correccion velocidad: ");
          Serial.println(vel_pid);
          Serial.print("Velocidad: ");
          Serial.println((vel_base + vel_pid));
        }
      }
      break;
  }
  /*
  derivada = error - error_previo;
  integral =+ error;
  pid_output = (Kp * error) + (Ki * (integral)) + (Kd * (derivada));
  */
}

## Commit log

2023-09-29 Corrección de errores
    Se agrego un Led de prueba para testear el funcionamiento del Esp32 WROOM y se corrigió la resistencia pull-up del pin BOOT
    [Repositor Automático V8 (Primer Final).kicad_pcb, Repositor Automático V8 (Primer Final).kicad_sch]
2023-10-02 Subiendo V2 de Página web
2023-10-11 Diseño final con correccion de Errores
    [Repositor Automático V8 (Primer Final).kicad_pcb, Repositor Automático V8 (Primer Final).kicad_sch]
2023-10-11 Correccion de errores diseño final
    [Repositor Automático V8 (Primer Final).kicad_pcb, Repositor Automático V8 (Primer Final).kicad_sch]
2023-10-11 Correccion IDC
    [Repositor Automático V8 (Primer Final).kicad_pcb]
2023-10-12 Correccion Serigrafía
    [Repositor Automático V8 (Primer Final).kicad_pcb]
2023-10-17 Agregue estilo para checkbox password
2023-10-17 Agregue funcion para mostrar ocultar contraseña
2023-10-19 Subo jpg de guardia imperial white - blue
2023-10-19 Agregue funcion checkeo de password y login
2023-10-19 Funciones para que el usuario complete el formulario y funciones casillas esteticas
2023-10-19 Modificacion estructura html para llenado de formulario
2023-10-20 Arreglo error de casillas sin completar
2023-10-20 Adapte codigo para q funcione con un solo archivo style
2023-10-20 Agregue estilos de log in
2023-10-21 Agregue elemento form para inputs log in - Modifique boton log in a elemento input
2023-11-02 Agregue pagina de inicio
2023-11-02 Modificaciones de estilos
2024-02-24 Update: Agregue evento conexion de usuarios, recuperar username de url y generar uuid
2024-02-24 Update: Cree lista de conexiones y de usuarios
2024-02-25 Update: Server escucha desconecciones de usuarios
2024-02-25 Agregue carpeta src de Product-Card react app
2024-02-25 Update: Componente Home se conectal ws server pasando username atraves de query
2024-02-26 Update: Componente Cart elimina productos del carrito y agregue leyenda cuando no hay productos en el carrito
2024-02-28 Update: ButtonCheckCart manda mensaje del carrito al server cuando se presiona
2024-02-28 Update: Al broker se manda un json con id, nombre y cantidad de un solo producto q se ordeno, ademas del username de la orden
2024-02-28 Update: Dentro de objeto user, product es un array, q va a contener el nombre, la id y la cantidad q se ordeno de todos los productos
2024-02-28 Update: Agregue for q crea un nuevo espacio en array products donde se guarda la id, nombre y cantidad de cada producto q llega del array message
2024-02-29 Update: En Cart se puede sumar la cantidad de unidades de los productos en el carrito
2024-02-29 Update: Agregue funcion para actualizar cart cuando se modifique la quantity de un producto
2024-02-29 Update: Componente ProductCard envia mensaje del producto ordenado dentro de array para compatibilidad con el server
2024-03-01 Update: Componente Cart puede restar quantity de un producto - Agregue tope minimo (1) y tope maximo (stock del producto) de las quantities de los productos - Agregue boton delete product
2024-03-01 Update: Agregue svg de botones cantidades y borrar producto de cart
2024-03-01 Fix: Ya no se sobre escribe la lista de productos q se envia al broker
2024-06-05 Update: Cree carpeta de archivos 3D stl - Agregue esquinero de la base 1
    [ESQUINERO-BASE-1.STL]
2024-06-05 Agregue README.md para piezas 3D
2024-06-05 Update: Agregue piezas de impresion 3d
    [SOPORTE-MOTORES.STL, SOPORTE-PLACA-CNY70.STL]
2024-06-17 Update: actualice pieza esquinero
    [ESQUINERO-BASE-1.STL]
2024-06-22 Update: actualice pieza - achique borde horizontal a 5mm y vertical a 6mm
    [ESQUINERO-BASE-1.STL]
2024-06-24 Update: agrande agujeros
    [ESQUINERO-BASE-1.STL]
2024-06-30 Update: agrande agujeros, agregue 2do agujero de base, modifique medidas del perfil, agregue espacio de margen para el motor
    [SOPORTE-MOTORES.STL]
2024-11-01 Add files via upload
    Subi soporte placa driver-main
    [SOPORTE-PLACA-DRIVER-MAIN.STL]
2024-11-02 Subí programa para probar drivers TB
2024-11-07 Agregue esquinero más largo
    [ESQUINERO-BASE-1-V2.STL]
2024-11-14 Actualización de repositorio
    [Repositor_Automático-Version_2024-1.kicad_pcb, Repositor_Automático-Version_2024-1.kicad_sch, Repositor_Automático-Version_2024-3(a_probar).kicad_pcb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]
